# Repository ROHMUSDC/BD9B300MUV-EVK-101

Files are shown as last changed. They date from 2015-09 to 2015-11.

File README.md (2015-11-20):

# BD9B300MUV-EVK-101 Design Resource Repository
* Hardware Design Files and Documentation for the ROHM BD9B300MUV-EVK-101 EVK

----
### Description: 
* BD9B300MUV is a synchronous buck switching regulator with built-in low on-resistance power MOSFETs
* This IC, capable of providing current up to 3A, features fast transient response by employing constant on-time control circuitry
* It offers high oscillating frequency at low inductance
* With ROHM's constant on-time control method which operates low consumption at light load, this product is ideal for equipment and devices that demand minimal standby power consumption.

----
### Repository Contents
* Application Note Folder: Contains Draft Version of EVK Application Note
* Design Files: Contains Board, Gerber, Schematic, and BOM information for this EVK Board
* Measurement Reports Folder: Contains measurement testing information completed for these EVK Boards

----
### Where to Purchase?
* http://www.rohm.com/web/global/distribution/-/dinventory/BD9B300MUV-EVK-101/sample/0 

----
### DISCLAIMER
This Technical Data is protected under copyright laws.

ROHM hereby grants you a nonexclusive, nontransferable license to use this Technical Data 
as long as you abide by the terms and conditions of this DISCLAIMER. 

However, you are not authorized to sell, loan, rent, lease, redistribute or license this Technical Data, 
in whole or in part, or in modified form, to anyone.

You may modify this Technical Data to suit your specific applications, 
but the rights to derivative works and said modifications shall belong to ROHM. 

You may make copies of this Technical Data as necessary for internal use only within your company.

In any case, the latest datasheet is considered the final design guideline and represents 
the only actual performance specifications.

ROHM shall not be responsible for ensuring proper application on all computer systems.
This Technical Data is provided AS IS. ROHM makes no guarantees, either implicitly or explicitly, 
regarding its usability, functionality, accuracy, merchantability, or fitness for a specific purpose.

In addition, you shall take full responsibility for the use of any information acquired from this Technical Data. 

ROHM does not assume warranty of any kind arising from the use of this Technical Data. ACCORDINGLY, 
IN NO EVENT SHALL ROHM BE RESPONSIBLE, WHETHER THROUGH CONTRACT OR TORT LIABILITY, 
FOR ANY DAMAGES (INCLUDING BUT NOT LIMITED TO LOST PROFITS OR OTHER INCIDENTAL, CONSEQUENTAL, 
OR PUNITIVE DAMAGES) ARISING OUT OF OR IN CONNECTION WITH THE USE OR APPLICATION OF THIS Technical Data.

Furthermore, this Technical Data is subject to change without notice.

Unless otherwise expressly provided herein, ROHM does not convey any license under patent rights 
or any other intellectual property rights (including those of third parties).

ROHM is not obligated to provide maintenance or support for the Technical Data.

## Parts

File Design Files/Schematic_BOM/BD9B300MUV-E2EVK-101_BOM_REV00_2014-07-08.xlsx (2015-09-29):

BD9B300MUV-E2EVK-101 Revised: Friday, June 20, 2014
Revision: 00
Bill Of Materials June 20,2014 15:54:18 | Page1
Item | Quantity | Reference | Part | PCB Footprint | DESCRIPTION | MFG1 | MFG1_PART# | DISTR1 | DISTR1_PART# | DNP | Provided by ROHM | ROHM Comment
1 | 1 | CR1 | SML-310MTT86 | LED_0603 | LED 570NM GREEN WTR CLR 0603 SMD | Rohm | SML-310MTT86 | DIGIKEY | 511-1299-1-ND |  | Y
2 | 1 | C1 | 10uF | C1206 | CAP CER 10UF 10V 10% X5R 1206 | Murata | GRM319R61A106KE19D | DIGIKEY | 490-3378-2-ND |  | Y
3 | 3 | C2,C3,C4 | 0.1uF | C0603 | CAP CER 0.1UF 16V 10% X7R 0603 | Murata | GRM188R71C104KA01D | DIGIKEY | 490-1532-2-ND |  | Y
4 | 2 | C5,C6 | 22uF | C1210 | CAP CER 22UF 6.3V 10% X5R 1210 | Murata | GRM32DR60J226KA01L | DIGIKEY | 490-1886-2-ND |  | Y
5 | 1 | C10 | 180pF | C0603 | CAP CER 180PF 50V 5% NP0 0603 | Murata | GRM1885C1H181JA01D | DIGIKEY | 490-1433-2-ND |  | Y
6 | 1 | D1 | P4SMA6.8A | DO-214AC | DIODE TVS 400W 6.8V UNI 5% SMD | Littelfuse Inc | P4SMA6.8A | DIGIKEY | F5656CT-ND |  | N
7 | 3 | J1,J2,J3 | 87224-3 | HDR_THVT_1X3_100 | CONN HEADER VERT .100 3POS 15AU | TE Connectivity | 87224-3 | DIGIKEY | A26545-ND |  | N
8 | 1 | L1 | 1.5uH | SMT_6P6x6P6 | INDUCTOR WW 1.5UH 8A SMD | Wurth | 74437349015 | DIGIKEY | 732-3351-2-ND |  | Y
9 | 1 | Q1 | SST2222AT116 | SOT23_BEC | TRANSISTOR NPN 40V 0.6A SOT-23 | Rohm | SST2222AT116 | DIGIKEY | SST2222AT116TR-ND |  | Y
10 | 1 | R1 | 140 | R0603 | RES 140 OHM 1/10W 1% 0603 SMD | Rohm | MCR03ERTF1400 | DIGIKEY | RHM140CFTR-ND |  | Y
11 | 1 | R2 | 100k | R0603 | RES 100K OHM 1/10W 5% 0603 SMD | Rohm | MCR03ERTJ104 | DIGIKEY | RHM100KCGTR-ND |  | Y
12 | 1 | R3 | 1k | R0603 | RES 1K OHM 1/10W 5% 0603 SMD | Rohm | MCR03ERTJ102 | DIGIKEY | RHM1.0KCGTR-ND |  | Y
13 | 1 | R4 | 160k | R0603 | RES 160K OHM 1/10W 1% 0603 SMD | Rohm | MCR03ERTF1603 | DIGIKEY | RHM160KCFTR-ND |  | Y
14 | 1 | R5 | 51k | R0603 | RES 51K OHM 1/10W 1% 0603 SMD | Rohm | MCR03ERTF5102 | DIGIKEY | RHM51KCFCT-ND |  | Y
15 | 3 | TP1,TP2,TP4 | TP_TH_63MIL_RED | TP_TH | TEST POINT PC MULTI PURPOSE RED | Keystone Electronics | 5010 | DIGIKEY | 5010K-ND |  | N
16 | 2 | TP3,TP5 | TP_TH_63MIL_BLK | TP_TH | TEST POINT PC MULTI PURPOSE BLK | Keystone Electronics | 5011 | DIGIKEY | 5011K-ND |  | N
17 | 1 | U1 | BD9B300MUV | VQFN016V3030 |  |  |  |  |  |  | Y
18 | 3 |  |  |  | Shunt jumper for header J1, J2, J3 (item #7), CONN SHUNT 2POS GOLD W/HANDLE | TE Connectivity | 881545-1 | DIGIKEY | 881545-1-ND |  | N
19 | 2 | C7,C11 |  | C0603 |  |  |  |  |  | Do Not Place
20 | 1 | C8 |  | C0805 |  |  |  |  |  | Do Not Place
21 | 1 | C9 |  | C1206 |  |  |  |  |  | Do Not Place

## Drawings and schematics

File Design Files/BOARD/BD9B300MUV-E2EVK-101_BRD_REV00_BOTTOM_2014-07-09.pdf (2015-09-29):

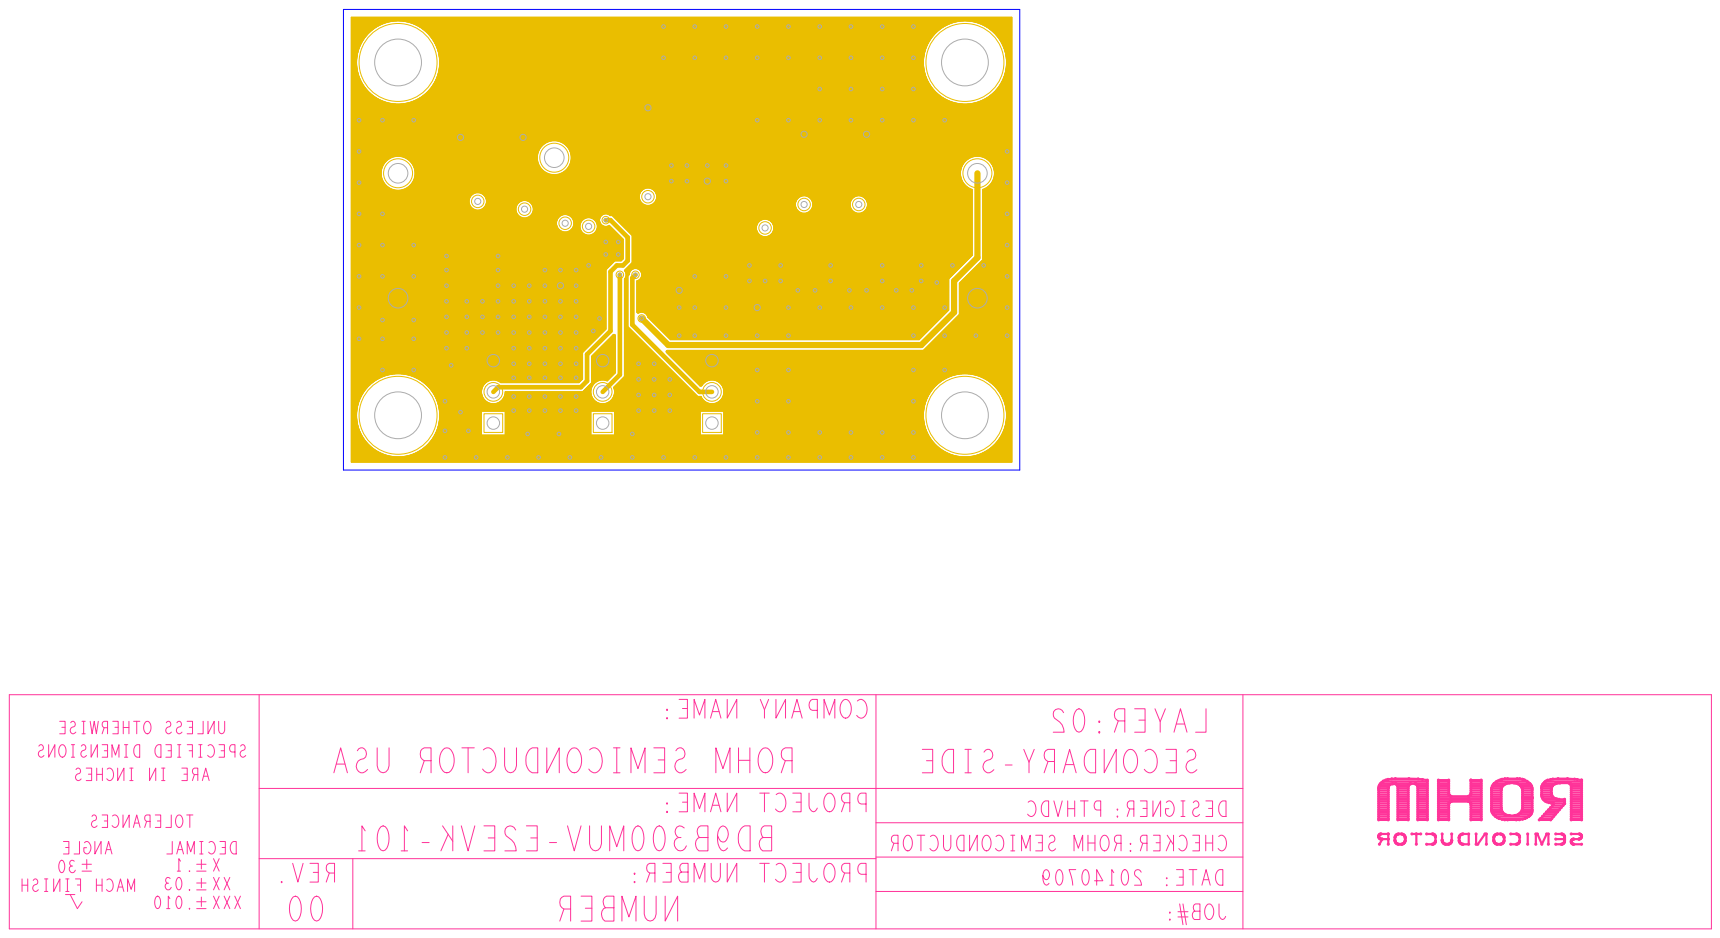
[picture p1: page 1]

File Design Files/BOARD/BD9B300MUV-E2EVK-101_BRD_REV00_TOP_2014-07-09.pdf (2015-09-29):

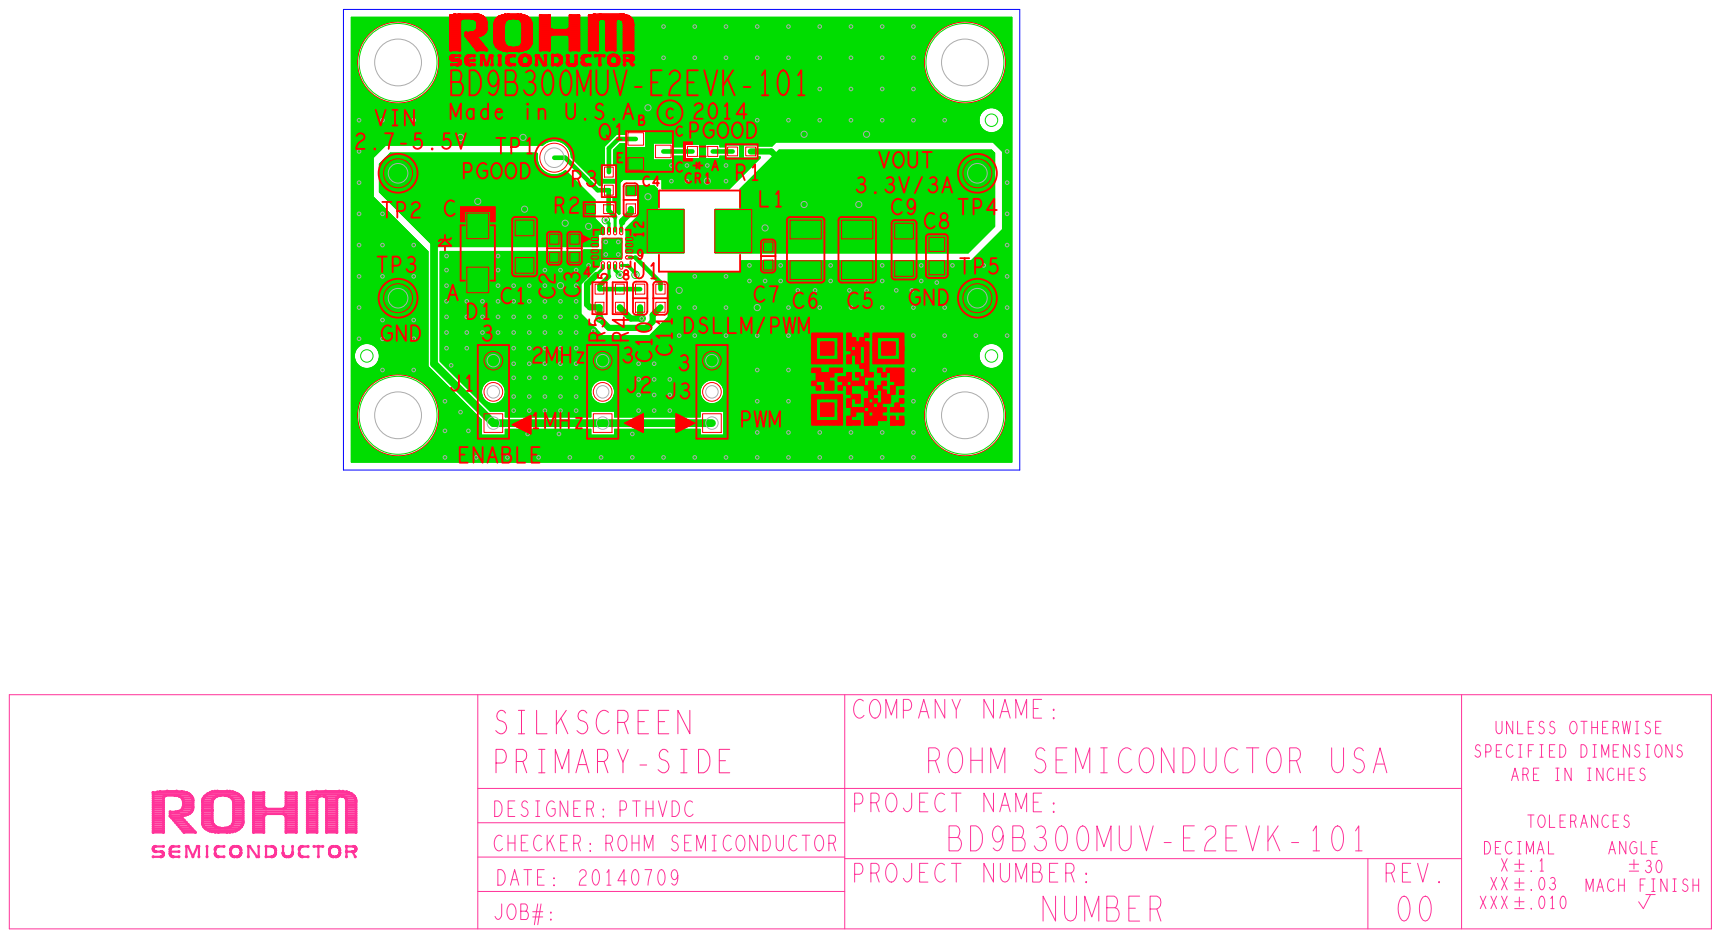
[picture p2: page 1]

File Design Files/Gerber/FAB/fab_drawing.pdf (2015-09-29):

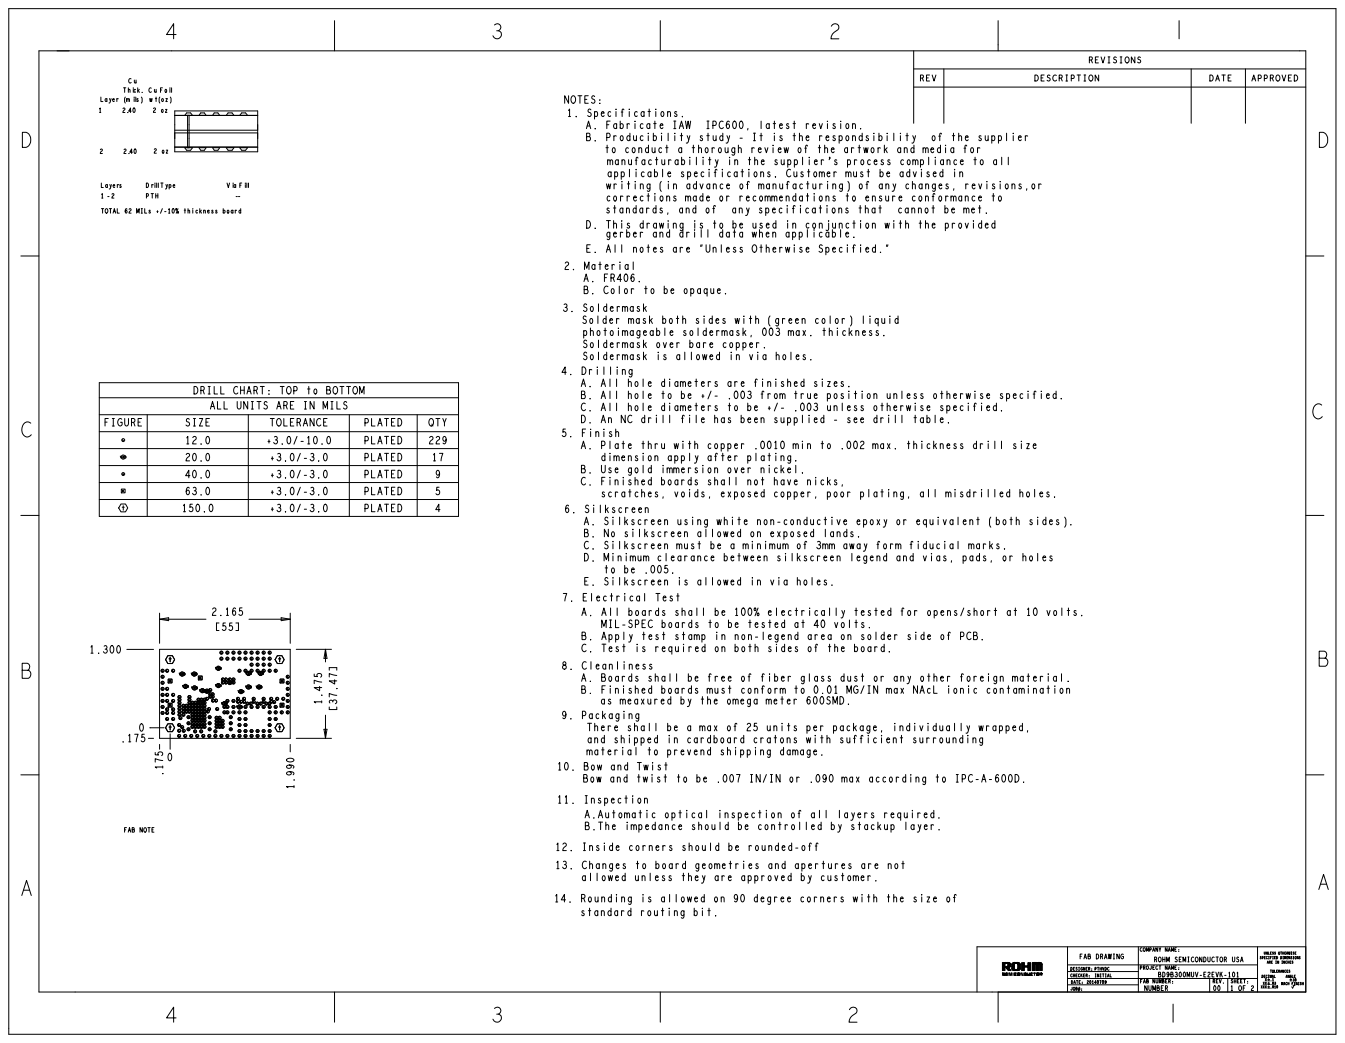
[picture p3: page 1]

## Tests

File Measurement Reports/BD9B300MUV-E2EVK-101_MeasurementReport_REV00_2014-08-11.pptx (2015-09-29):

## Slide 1

PTH Solutions Confidential

BD9B300MUV-E2EVK-101 Measurement Report
August 11, 2014
Hosted by: Xuan Dang & Vu Phan

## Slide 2

Equipment list

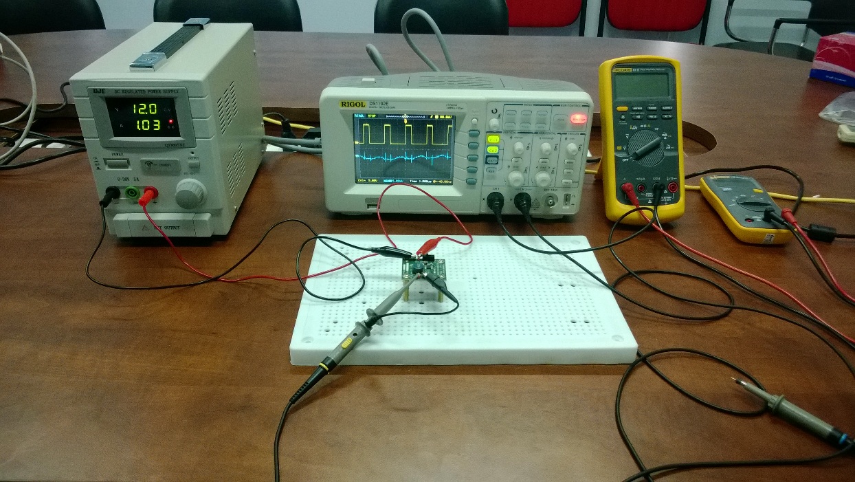
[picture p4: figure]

- Regulated DC Power Supply
  - QJE QJ3005XE (0-30V/5A)
- Multimeter:
  - Fluke 87V True RMS
  - Fluke 106
- Oscilloscope
  - Rigol DS1102E
- Electronic Load
  - B&K BK8500
- Current probe
  - RP1001C

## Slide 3

1. Functional Test

- Testing procedure
  1. Turn on the DC Supply. Set output of the DC Supply in range from 2.7V to 5.5V and turn it off. Connect DC the Supply to: [+]VIN(TP2) and [-]GND(TP3) of evaluation board.
  2. Connect Electronic Load to: [+]VOUT(TP4) and [-]GND(TP5). Power on Electronic Load, set input of Electronic Load to 3A.
  3. Set constant on-time and operation mode of device.
  4. Turn on the DC Supply.
  5. Turn on load.
  6. Move header J1 to turn EN on.

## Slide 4

1. Functional Test (cont.)

- Result:
  - VIN = 5V
  - IOUT = 3A

FREQ (Set by header J2) | MODE (Set by header J3) | VOUT | Result
2.0MHz (FREQ=L) | DSLLM/PWM (MODE=L) | 3.32V | Passed
2.0MHz (FREQ=L) | PWM (MODE=H) | 3.31V | Passed
1.0MHz (FREQ=H) | DSLLM/PWM (MODE=L) | 3.31V | Passed
1.0MHz (FREQ=H) | PWM (MODE=H) | 3.31V | Passed

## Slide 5

2. Hot Plugging Test

- Test condition
  - VIN = 5.5V
  - IOUT = 3A
  - With original diode D1: P4SMA6.8A
- Result:
- IIN_MAX= 21.4A
- VIN peak transient voltage is 7.6V > VIN Maximum Rating (7V)
- The IC still operate properly after 100+ test time.

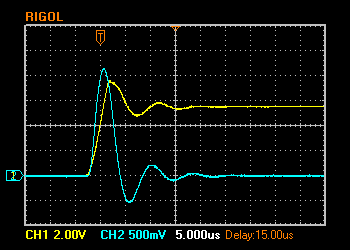
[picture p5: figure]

VIN 2V/Div. (DC)

IIN 5A/Div. (AC)

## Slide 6

3. Circuit Quiescent Current Measurement

- Test condition
  - VIN = 0-5.5V
  - Room temperature 25oC

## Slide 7

4. Efficiency Measurements

- Test condition
  - VIN = 5V
  - VOUT = 3.3V
  - With P4SMA6.8A
  - Room temperature 25oC

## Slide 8

5. Load Response Measurements

Load response characteristic
(VIN=5V, VOUT=3.3V, IOUT=0 → 3A, FREQ=L, MODE=L)

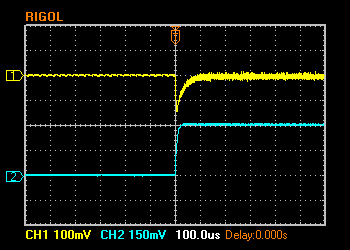
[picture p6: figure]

VOUT 100mV/Div. (AC)

IOUT 1.5A/Div. (DC)

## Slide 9

5. Load Response Measurements (cont.)

Load response characteristic
(VIN=5V, VOUT=3.3V, IOUT=3A → 0, FREQ=L, MODE=L)

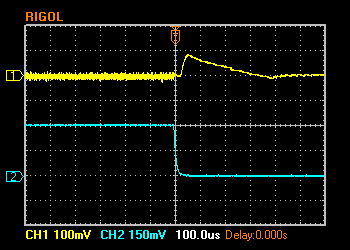
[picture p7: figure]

VOUT 100mV/Div. (AC)

IOUT 1.5A/Div. (DC)

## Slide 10

5. Load Response Measurements (cont.)

Load response characteristic
(VIN=5V, VOUT=3.3V, IOUT=0 → 3A, FREQ=L, MODE=H)

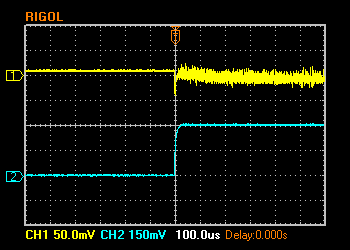
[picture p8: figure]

VOUT 50mV/Div. (AC)

IOUT 1.5A/Div. (DC)

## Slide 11

5. Load Response Measurements (cont.)

Load response characteristic
(VIN=5V, VOUT=3.3V, IOUT=3A → 0, FREQ=L, MODE=H)

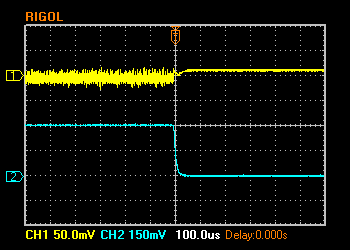
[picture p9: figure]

VOUT 50mV/Div. (AC)

IOUT 1.5A/Div. (DC)

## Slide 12

5. Load Response Measurements (cont.)

Load response characteristic
(VIN=5V, VOUT=3.3V, IOUT=0 → 3A, FREQ=H, MODE=L)

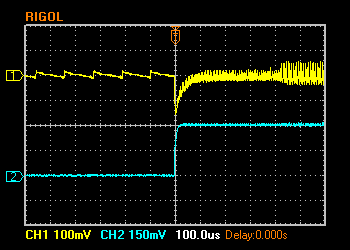
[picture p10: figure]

VOUT 100mV/Div. (AC)

IOUT 1.5A/Div. (DC)

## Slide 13

5. Load Response Measurements (cont.)

Load response characteristic
(VIN=5V, VOUT=3.3V, IOUT=3A → 0, FREQ=H, MODE=L)

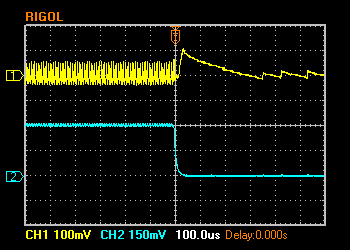
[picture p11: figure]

VOUT 100mV/Div. (AC)

IOUT 1.5A/Div. (DC)

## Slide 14

5. Load Response Measurements (cont.)

Load response characteristic
(VIN=5V, VOUT=3.3V, IOUT=0 → 3A, FREQ=H, MODE=H)

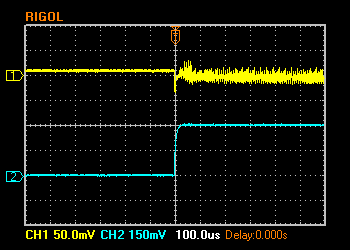
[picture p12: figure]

VOUT 50mV/Div. (AC)

IOUT 1.5A/Div. (DC)

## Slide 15

5. Load Response Measurements (cont.)

Load response characteristic
(VIN=5V, VOUT=3.3V, IOUT=3A → 0, FREQ=H, MODE=H)

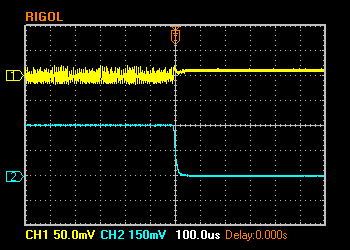
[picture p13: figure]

VOUT 50mV/Div. (AC)

IOUT 1.5A/Div. (DC)

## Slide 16

6. Ripple Response Measurements

VOUT Ripple voltage
(VIN=5V, VOUT=3.3V, IOUT=0, FREQ=L, MODE=L)


VSW 2V/Div. (DC)

VOUT 10mV/Div. (AC)

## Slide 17

6. Ripple Response Measurements (cont.)

VOUT Ripple voltage
(VIN=5V, VOUT=3.3V, IOUT=3A, FREQ=L, MODE=L)


VSW 2V/Div. (DC)

VOUT 20mV/Div. (AC)

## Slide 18

6. Ripple Response Measurements (cont.)

VOUT Ripple voltage
(VIN=5V, VOUT=3.3V, IOUT=0, FREQ=L, MODE=H)


VSW 2V/Div. (DC)

VOUT 20mV/Div. (AC)

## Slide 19

6. Ripple Response Measurements (cont.)

VOUT Ripple voltage
(VIN=5V, VOUT=3.3V, IOUT=3A, FREQ=L, MODE=H)


VSW 2V/Div. (DC)

VOUT 20mV/Div. (AC)

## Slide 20

6. Ripple Response Measurements (cont.)

VOUT Ripple voltage
(VIN=5V, VOUT=3.3V, IOUT=0, FREQ=H, MODE=L)


VSW 2V/Div. (DC)

VOUT 20mV/Div. (AC)

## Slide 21

6. Ripple Response Measurements (cont.)

VOUT Ripple voltage
(VIN=5V, VOUT=3.3V, IOUT=3A, FREQ=H, MODE=L)


VSW 2V/Div. (DC)

VOUT 50mV/Div. (AC)

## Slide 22

6. Ripple Response Measurements (cont.)

VOUT Ripple voltage
(VIN=5V, VOUT=3.3V, IOUT=0, FREQ=H, MODE=H)


VSW 2V/Div. (DC)

VOUT 20mV/Div. (AC)

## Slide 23

6. Ripple Response Measurements (cont.)

VOUT Ripple voltage
(VIN=5V, VOUT=3.3V, IOUT=3A, FREQ=H, MODE=H)


VSW 2V/Div. (DC)

VOUT 20mV/Div. (AC)
